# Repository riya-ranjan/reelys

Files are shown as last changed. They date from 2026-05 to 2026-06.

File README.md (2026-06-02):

# Reelys

Reelys are a DIY sonified, light up heely shoe, designed from scratch as part of a capstone project for Stanford CCRMA's MUSIC250A: Physical Interaction Design for Music. 

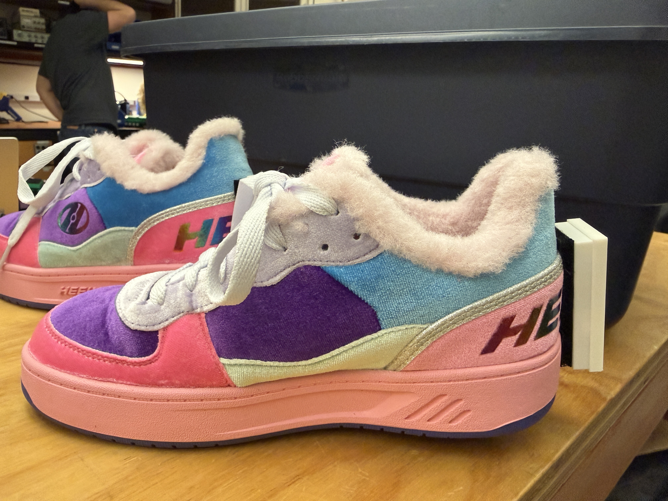
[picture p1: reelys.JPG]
REELYS


## Hardware/Electronics
  * [Seeed XIAO nRF52840 Sense x2](https://www.seeedstudio.com/Seeed-XIAO-BLE-Sense-nRF52840-p-5253.html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)
  * [Rechargeable Lithium Polymer Battery x2](https://ydlbattery.com/products/ydl-3-7v-150mah-352025-rechargeable-lipo-battery-with-jst-connector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)
  * [Adapter Cables Polymer Battery x2](https://www.amazon.com/dp/B07NWD5NTN?ref=ppx_yo2ov_dt_b_fed_asin_title)
  * 1 pair of your favorite Heelys. I got [these](https://heelys.com/products/rezerve-low-neon-pink-violet-aruba?variant=45104283877527) since they were only 30 bucks on sale.
  * Casings for the chips + batteries to velcro to the back of the shoe. See `assembly/Reelys-Casing-Final.stl` for a 3D print you can use for this. 

## Software

This project uses Arduino code for obtaining IMU readings from the Seeed boards, and Max for doing sound synthesis. 

## Arduino and Python Libraries

**Board package** (install via Arduino IDE → Tools → Board → Boards Manager…):

  * **Seeed nRF52 Boards** — v1.1.12.
    To make the package available in Boards Manager, first add the index URL under **Arduino IDE → Settings → Additional boards manager URLs**:
    `https://files.seeedstudio.com/arduino/package_seeeduino_boards_index.json`

**Libraries** (install via Arduino IDE → Tools → Manage Libraries…):

  * **Seeed Arduino LSM6DS3** — v2.0.5. Driver for the onboard LSM6DS3TR-C IMU.
    https://github.com/Seeed-Studio/Seeed_Arduino_LSM6DS3
  * **MIDI Library** by Francois Best / lathoub — v5.0.2. Wraps Bluefruit's `BLEMidi` transport so the standard `MIDI.sendControlChange(...)` API works over BLE.

**Python (laptop side, debug listener only)** — pinned in `requirements.txt`:

  * **bleak** ≥0.21. If you are using `tools/ble_listener.py` to debug bluetooth connections to your Reelys, install with `pip install -r requirements.txt`.

## Usage

Flash both of your Seeed chips using `test_sketches/imu_ble_midi.ino`. Make sure that you change the 
shoe identity variable at the top of the file between flashes (1 for right shoe, 0 for left shoe).

Once you have your IMUs powered on and strapped to the back of the shoe, they should be recognizable
as `Reelys-L` and `Reelys-R` bluetooth MIDI devices. On Mac, you can connect to these devices using
the Audio Midi Setup app and opening up bluetooth connections in the MIDI Studio. 

Once your bluetooth connection is set up, you can launch the `max_patches/wee_oo.maxpat` patch and hear
sound from both shoes. You may need to recalibrate the patch to the orientation of your Seeed; mine is 
calibrated to changes in z acceleration. Feel free to create your own patches for customized sound design! 

To recharge your batteries, make sure they are connected to your Seeed chip and plug your Seeed chip
into your laptop via the USB-C connection.

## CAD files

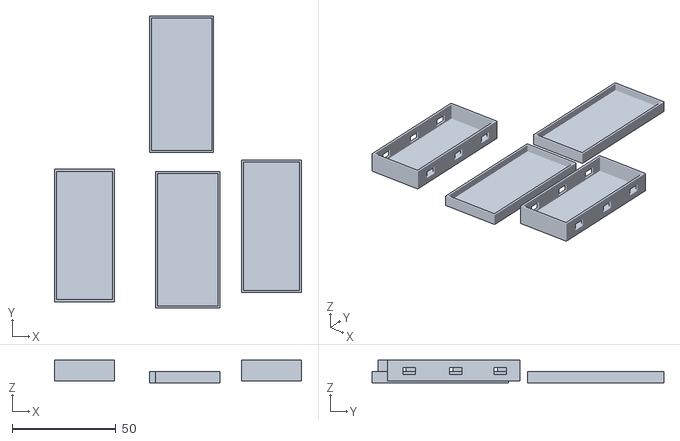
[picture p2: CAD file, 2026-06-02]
assembly/Reelys-Casing-Final.stl
119.5 x 141.0 x 11.0

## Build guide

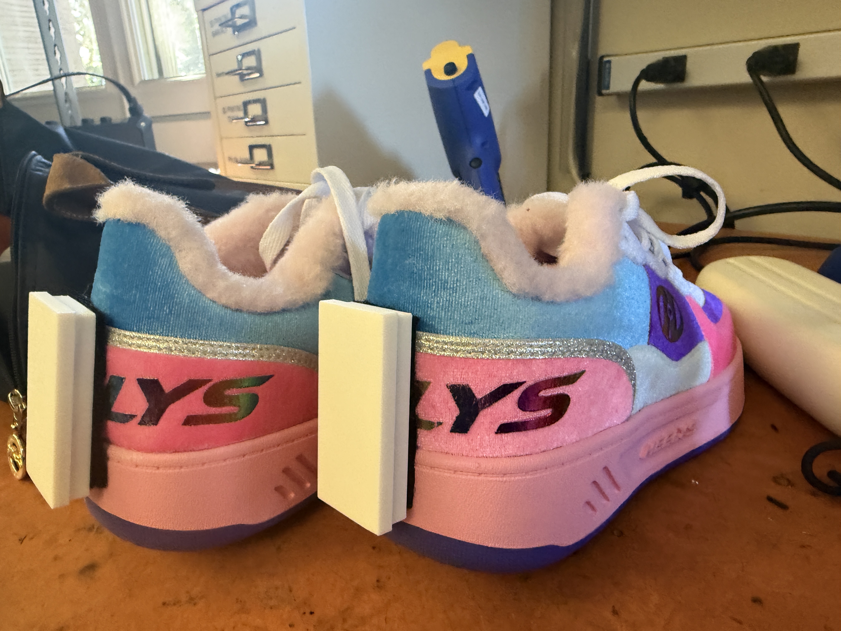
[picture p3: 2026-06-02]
assembly/FINISHED.JPG

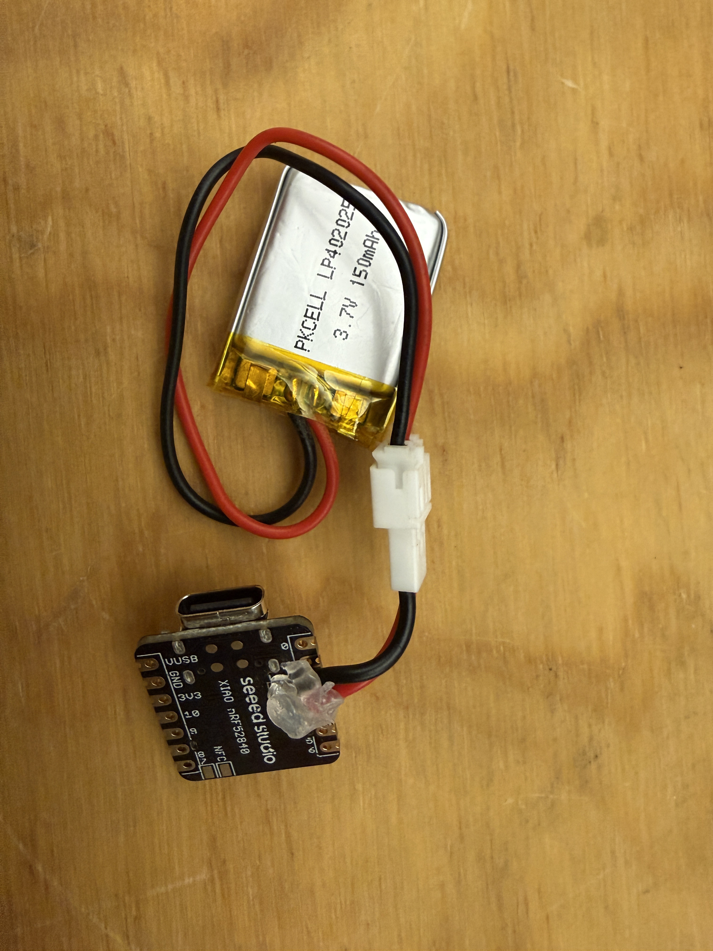
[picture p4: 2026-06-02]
assembly/ELECTRIC_CONNECTION.JPG

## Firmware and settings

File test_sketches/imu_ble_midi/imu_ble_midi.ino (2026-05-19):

// Reelys — imu_ble_midi
// Read the onboard LSM6DS3TR-C IMU on the Seeed XIAO nRF52840 Sense at
// ~50 Hz, advertise as a standard BLE MIDI peripheral, and stream each
// axis as a 7-bit MIDI CC. Keep echoing the same CSV to USB serial so
// the imu_serial manual test still works when plugged in.
//
// This sketch is mutually exclusive with imu_ble.ino — they advertise
// the same device name but expose different BLE services. Flash this
// one when you want sound out of Max; reflash imu_ble.ino if you need
// the raw-float Python debug pipeline.
//
// Change detection / hysteresis:
//   The LSM6DS3 is very sensitive — a stationary shoe still produces
//   small jitter in the IMU readings. Sending a CC for every sample
//   would flood Max with ~300 msg/s of mostly-redundant updates. So
//   each CC is only sent when its newly-scaled 7-bit value differs
//   from the last *sent* value by at least CC_DELTA_THRESHOLD LSBs.
//   At rest: near-zero BLE traffic. In motion: bounded at 6 msgs per
//   sample × 50 Hz = 300 msg/s worst case.
//   Tune CC_DELTA_THRESHOLD up if Max still feels jittery, or down
//   (to 1) if small gestures aren't moving the CCs.
//
// Build / upload:
//   Board:     Tools → Board → Seeed nRF52 Boards → "Seeed XIAO nRF52840 Sense"
//   Libraries: - "Seeed Arduino LSM6DS3" via Library Manager (same as imu_ble)
//              - "MIDI Library" by FortySevenEffects via Library Manager  <-- NEW
//                https://github.com/FortySevenEffects/arduino_midi_library
//              The Bluefruit nRF52 library is bundled with the Seeed nRF52
//              board package — no separate install needed.
//   Upload:    Upload (→) in the IDE; double-tap reset if it doesn't enumerate.
//
// Pair on macOS:
//   1. Open Audio MIDI Setup.app → Window → Show MIDI Studio.
//   2. Double-click the "Bluetooth" icon.
//   3. "Reelys-L" should appear in the device list — click "Connect".
//   4. The shoe is now a system-wide MIDI source. Any DAW or Max patch
//      can read its CCs via standard MIDI input.
//
// Verify in Max:
//   With one shoe connected: drop six [ctlin N] objects (N=1..6), each into
//   a number box. Right-click each ctlin → Input → select the shoe's name
//   ("Reelys-L" or "Reelys-R") to avoid crosstalk with other MIDI devices.
//   With both shoes connected: use [ctlin N C] where C is the channel
//   (1 for left, 2 for right) — e.g. [ctlin 1 1] for left ax, [ctlin 1 2]
//   for right ax. Channel filtering is how Max distinguishes the two shoes.
//   Wiggle the shoe — values should update when motion exceeds the
//   hysteresis threshold (default 2 LSB on a 0–127 scale).
//
// BLE protocol:
//   Device name:    "Reelys-L"  (left shoe; right shoe will use "-R")
//   Service UUID:   03B80E5A-EDE8-4B33-A024-BC7BDC5DA0EF  (standard BLE MIDI)
//   Char   UUID:    7772E5DB-3868-4112-A1A9-F2669D106BF3  (standard BLE MIDI)
//   These UUIDs come from Apple's BLE MIDI 1.0 spec — do not invent custom ones.
//
// Shoe identity (build-time switch):
//   Flip the REELYS_SHOE_RIGHT macro near the top of the code from 0 to 1
//   before flashing the *right* shoe. That selects:
//     0 → device name "Reelys-L", MIDI channel 1  (default; left shoe)
//     1 → device name "Reelys-R", MIDI channel 2  (right shoe)
//   CC numbers (1..6) are identical on both shoes; Max distinguishes left
//   vs right by channel. The sketch is otherwise identical between shoes,
//   so any future tweak (hysteresis, sample rate, scaling) lives in one
//   place and applies to both. Remember to flip the macro back to 0 before
//   reflashing the left shoe.
//
// Calibration — tilt-focused:
//   The accel range is clamped to ±1 g, not the full ±16 g the sensor reports.
//   Rationale: gravity projected onto any single axis is always within ±1 g,
//   so for tilt sensing the entire 0..127 CC range is spent on orientation
//   instead of wasted on impact headroom. The tradeoff is that any accel
//   spike above 1 g (heel-strike, stomp) saturates the accel CCs at 0 or 127.
//   This is intentional — stomp / impact handling will widen the range later.
//   Gyro stays at ±2000°/s (still useful as "how fast the shoe is rotating").
//
// MIDI CC mapping (channel 1):
//   CC 1 → ax (accel X, forward)   range ±1 g     mapped to 0..127
//   CC 2 → ay (accel Y, lateral)   range ±1 g     mapped to 0..127
//   CC 3 → az (accel Z, vertical)  range ±1 g     mapped to 0..127
//   CC 4 → gx (gyro X)             range ±2000°/s mapped to 0..127
//   CC 5 → gy (gyro Y)             range ±2000°/s mapped to 0..127
//   CC 6 → gz (gyro Z)             range ±2000°/s mapped to 0..127
//   Stationary, shoe flat: CC1/CC2 ≈ 64, CC3 ≈ 127 (1 g of gravity pins az
//   to the top of the ±1 g range), CC4..6 ≈ 64. Tilting the shoe sweeps
//   CC1/CC2 across the full 0..127 range as the gravity vector rotates.
//
// CSV format (USB serial, one line per sample — unchanged from imu_serial /
// imu_ble, and printed every sample regardless of BLE connection state):
//   timestamp_ms,ax,ay,az,gx,gy,gz

#include <bluefruit.h>
#include <MIDI.h>
#include "LSM6DS3.h"
#include "Wire.h"

// ---------------- Shoe identity (build-time) ----------------

// Flip to 1 before flashing the right shoe; flip back to 0 before flashing
// the left shoe. See the "Shoe identity" block in the header comment.
#define REELYS_SHOE_RIGHT 1

#if REELYS_SHOE_RIGHT
  static const char*   REELYS_DEVICE_NAME = "Reelys-R";
  static const uint8_t MIDI_CHANNEL       = 2;
#else
  static const char*   REELYS_DEVICE_NAME = "Reelys-L";
  static const uint8_t MIDI_CHANNEL       = 1;
#endif

// ---------------- IMU ----------------
static LSM6DS3 imu(I2C_MODE, 0x6A);
static const unsigned long SAMPLE_PERIOD_MS = 20;  // ~50 Hz

// ---------------- MIDI mapping ----------------

// Accel clamp is set to ±1 g — tilt-focused. See the "Calibration" block in
// the header comment for the full rationale and the impact-saturation tradeoff.
static const float   ACCEL_RANGE_G   = 1.0f;
static const float   GYRO_RANGE_DPS  = 2000.0f;
// MIDI_CHANNEL is defined in the "Shoe identity" block above (1 = left, 2 = right).

// CC numbers per IMU axis, in [ax, ay, az, gx, gy, gz] order.
static const uint8_t CC_NUMS[6] = { 1, 2, 3, 4, 5, 6 };

// Hysteresis on the 7-bit CC value — only send when the new scaled value
// has moved at least this many LSBs from the last sent value. 2 LSB on a
// 0..127 scale is ~1.6% of full range, enough to swallow stationary IMU
// jitter while still catching small intentional gestures.
static const int CC_DELTA_THRESHOLD = 2;

// Sentinel 255 is out-of-range for a 7-bit CC, so the first scaled sample
// always exceeds the delta threshold and is sent — that gives Max a baseline.
static uint8_t cc_last[6] = { 255, 255, 255, 255, 255, 255 };

// ---------------- BLE MIDI ----------------

static BLEDis   bledis;
static BLEMidi  blemidi;
MIDI_CREATE_BLE_INSTANCE(blemidi);

// ---------------- helpers ----------------

static void halt(const char* reason) {
  for (;;) {
    Serial.print("[FATAL] ");
    Serial.println(reason);
    delay(1000);
  }
}

// Map a signed float into a 7-bit MIDI CC value with hard clamping.
// 0 maps to 64 (mid-range), ±range_abs maps to 0/127.
static uint8_t scaleToCC(float value, float range_abs) {
  if (value >  range_abs) value =  range_abs;
  if (value < -range_abs) value = -range_abs;
  float normalized = (value + range_abs) / (2.0f * range_abs);  // 0..1
  int cc = (int)(normalized * 127.0f + 0.5f);
  if (cc < 0)   cc = 0;
  if (cc > 127) cc = 127;
  return (uint8_t)cc;
}

static void startAdvertising() {
  Bluefruit.Advertising.addFlags(BLE_GAP_ADV_FLAGS_LE_ONLY_GENERAL_DISC_MODE);
  Bluefruit.Advertising.addTxPower();
  Bluefruit.Advertising.addService(blemidi);
  Bluefruit.ScanResponse.addName();  // name in scan response keeps adv packet under 31 bytes
  Bluefruit.Advertising.restartOnDisconnect(true);
  Bluefruit.Advertising.setInterval(32, 244);   // units of 0.625 ms → 20–152.5 ms
  Bluefruit.Advertising.setFastTimeout(30);
  Bluefruit.Advertising.start(0);               // 0 = advertise forever
}

// ---------------- Arduino entrypoints ----------------

void setup() {
  Serial.begin(115200);
  unsigned long t0 = millis();
  while (!Serial && (millis() - t0) < 2000) {
    delay(10);
  }

  if (imu.begin() != 0) {
    halt("LSM6DS3 init failed");
  }

  // BANDWIDTH_MAX must be set before Bluefruit.begin(). Not strictly required
  // for BLE MIDI's tiny 5-byte packets, but matches imu_ble and gives headroom
  // if all six CCs ever bundle into one connection event during fast motion.
  Bluefruit.configPrphBandwidth(BANDWIDTH_MAX);

  if (!Bluefruit.begin()) {
    halt("Bluefruit init failed");
  }
  Bluefruit.setName(REELYS_DEVICE_NAME);
  Bluefruit.setTxPower(4);  // dBm

  bledis.setManufacturer("Reelys");
  bledis.setModel(REELYS_DEVICE_NAME);
  bledis.begin();

  // MIDI.begin() internally calls blemidi.begin() to register the GATT service.
  // OMNI just controls input filtering — we only send, so it's a no-op for us.
  MIDI.begin(MIDI_CHANNEL_OMNI);

  startAdvertising();

  Serial.println("# Reelys / imu_ble_midi");
  Serial.println("# Streaming IMU over BLE MIDI + USB serial");
  Serial.print  ("# Device name: ");
  Serial.print  (REELYS_DEVICE_NAME);
  Serial.println(" (BLE MIDI peripheral)");
  Serial.println("# Sample rate: ~50 Hz");
  Serial.println("# CC hysteresis: 2 LSB (sends suppressed below threshold)");
  Serial.println("# Units: accel in g, gyro in deg/s");
  Serial.print  ("# CC mapping: CC1=ax CC2=ay CC3=az CC4=gx CC5=gy CC6=gz (ch ");
  Serial.print  (MIDI_CHANNEL);
  Serial.println(")");
  Serial.println("timestamp_ms,ax,ay,az,gx,gy,gz");
}

void loop() {
  unsigned long t = millis();

  float data[6];
  data[0] = imu.readFloatAccelX();
  data[1] = imu.readFloatAccelY();
  data[2] = imu.readFloatAccelZ();
  data[3] = imu.readFloatGyroX();
  data[4] = imu.readFloatGyroY();
  data[5] = imu.readFloatGyroZ();

  // Always print raw CSV to USB serial — independent of BLE state — so the
  // imu_serial manual test still works when plugged in for debugging.
  Serial.print(t);
  for (int i = 0; i < 6; i++) {
    Serial.print(',');
    Serial.print(data[i], 4);
  }
  Serial.println();

  // Stream changed CCs over BLE MIDI when a central is connected and ready.
  if (Bluefruit.connected() && blemidi.notifyEnabled()) {
    const float ranges[6] = {
      ACCEL_RANGE_G, ACCEL_RANGE_G, ACCEL_RANGE_G,
      GYRO_RANGE_DPS, GYRO_RANGE_DPS, GYRO_RANGE_DPS,
    };
    for (int i = 0; i < 6; i++) {
      uint8_t cc_new = scaleToCC(data[i], ranges[i]);
      int delta = (int)cc_new - (int)cc_last[i];
      if (delta < 0) delta = -delta;
      if (delta >= CC_DELTA_THRESHOLD) {
        MIDI.sendControlChange(CC_NUMS[i], cc_new, MIDI_CHANNEL);
        cc_last[i] = cc_new;
      }
    }
  }

  unsigned long elapsed = millis() - t;
  if (elapsed < SAMPLE_PERIOD_MS) {
    delay(SAMPLE_PERIOD_MS - elapsed);
  }
}

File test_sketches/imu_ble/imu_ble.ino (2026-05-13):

// Reelys — imu_ble
// Read the onboard LSM6DS3TR-C IMU on the Seeed XIAO nRF52840 Sense
// at ~50 Hz, stream samples over BLE as notifications, and keep
// echoing the same CSV to USB serial (so the imu_serial manual test
// still works when plugged in).
//
// Build / upload:
//   Board:    Tools → Board → Seeed nRF52 Boards → "Seeed XIAO nRF52840 Sense"
//   Library:  "Seeed Arduino LSM6DS3" via Library Manager.
//             The Bluefruit nRF52 library is bundled with the board package
//             — no separate install needed.
//   Upload:   Upload (→) in the IDE; double-tap reset if it doesn't enumerate.
//
// Observe:
//   - USB:    Tools → Serial Monitor, baud 115200. Same CSV format as imu_serial.
//   - BLE:    nRF Connect on phone → scan → "Reelys-L" should appear.
//             Connect, expand the custom service, enable notifications on the
//             characteristic to see 24-byte payloads stream in.
//   - Laptop: tools/ble_listener.py (added in the next step).
//
// BLE protocol:
//   Device name:        "Reelys-L"  (left shoe; right shoe will use "-R")
//   Service UUID:       9E6647DB-3EEC-42B6-8349-A95113E65082
//   Char   UUID:        AE7799DA-9123-45D5-84F9-20B5C3F7F6F4
//   Char   properties:  NOTIFY (no read/write)
//   Payload:            24 bytes = 6 IEEE 754 floats, little-endian, in order
//                       ax, ay, az, gx, gy, gz
//                       accel in g, gyro in deg/s
//
// CSV format (USB serial, one line per sample):
//   timestamp_ms,ax,ay,az,gx,gy,gz

#include <bluefruit.h>
#include "LSM6DS3.h"
#include "Wire.h"

// ---------------- IMU ----------------

static LSM6DS3 imu(I2C_MODE, 0x6A);
static const unsigned long SAMPLE_PERIOD_MS = 20;  // ~50 Hz

// ---------------- BLE ----------------

// 128-bit UUIDs in little-endian (wire) byte order — i.e. the textual
// UUID with its bytes reversed. The "human" UUIDs are in the header
// comment above. Don't edit one without updating the other.

// Service: 9E6647DB-3EEC-42B6-8349-A95113E65082
static const uint8_t SERVICE_UUID[16] = {
  0x82, 0x50, 0xE6, 0x13, 0x51, 0xA9, 0x49, 0x83,
  0xB6, 0x42, 0xEC, 0x3E, 0xDB, 0x47, 0x66, 0x9E
};

// Characteristic: AE7799DA-9123-45D5-84F9-20B5C3F7F6F4
static const uint8_t IMU_CHAR_UUID[16] = {
  0xF4, 0xF6, 0xF7, 0xC3, 0xB5, 0x20, 0xF9, 0x84,
  0xD5, 0x45, 0x23, 0x91, 0xDA, 0x99, 0x77, 0xAE
};

static BLEService        imuService(SERVICE_UUID);
static BLECharacteristic imuChar(IMU_CHAR_UUID);

// ---------------- helpers ----------------

static void halt(const char* reason) {
  for (;;) {
    Serial.print("[FATAL] ");
    Serial.println(reason);
    delay(1000);
  }
}

static void startAdvertising() {
  Bluefruit.Advertising.addFlags(BLE_GAP_ADV_FLAGS_LE_ONLY_GENERAL_DISC_MODE);
  Bluefruit.Advertising.addTxPower();
  Bluefruit.Advertising.addService(imuService);
  Bluefruit.ScanResponse.addName();  // name in scan response keeps adv packet under 31 bytes
  Bluefruit.Advertising.restartOnDisconnect(true);
  Bluefruit.Advertising.setInterval(32, 244);   // units of 0.625 ms → 20–152.5 ms
  Bluefruit.Advertising.setFastTimeout(30);
  Bluefruit.Advertising.start(0);               // 0 = advertise forever
}

// ---------------- Arduino entrypoints ----------------

void setup() {
  Serial.begin(115200);
  unsigned long t0 = millis();
  while (!Serial && (millis() - t0) < 2000) {
    delay(10);
  }

  if (imu.begin() != 0) {
    halt("LSM6DS3 init failed");
  }

  // Must be set before Bluefruit.begin(). Default ATT MTU is 23, which leaves
  // only 20 bytes for notification payloads — our 24-byte payload gets
  // truncated. BANDWIDTH_MAX bumps the peripheral MTU to 247 so notifications
  // can carry the full 24 bytes once the central negotiates upward.
  Bluefruit.configPrphBandwidth(BANDWIDTH_MAX);

  if (!Bluefruit.begin()) {
    halt("Bluefruit init failed");
  }
  Bluefruit.setName("Reelys-L");
  Bluefruit.setTxPower(4);  // dBm

  imuService.begin();

  imuChar.setProperties(CHR_PROPS_NOTIFY);
  imuChar.setPermission(SECMODE_OPEN, SECMODE_NO_ACCESS);
  imuChar.setFixedLen(24);  // 6 floats
  imuChar.begin();

  startAdvertising();

  Serial.println("# Reelys / imu_ble");
  Serial.println("# Streaming IMU over BLE + USB serial");
  Serial.println("# Device name: Reelys-L");
  Serial.println("# Sample rate: ~50 Hz");
  Serial.println("# Units: accel in g, gyro in deg/s");
  Serial.println("timestamp_ms,ax,ay,az,gx,gy,gz");
}

void loop() {
  unsigned long t = millis();

  float data[6];
  data[0] = imu.readFloatAccelX();
  data[1] = imu.readFloatAccelY();
  data[2] = imu.readFloatAccelZ();
  data[3] = imu.readFloatGyroX();
  data[4] = imu.readFloatGyroY();
  data[5] = imu.readFloatGyroZ();

  if (Bluefruit.connected()) {
    imuChar.notify(data, sizeof(data));
  }

  Serial.print(t);
  for (int i = 0; i < 6; i++) {
    Serial.print(',');
    Serial.print(data[i], 4);
  }
  Serial.println();

  unsigned long elapsed = millis() - t;
  if (elapsed < SAMPLE_PERIOD_MS) {
    delay(SAMPLE_PERIOD_MS - elapsed);
  }
}

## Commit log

2026-05-13 basic files to read from XIAO IMU
2026-05-22 arduino / python library spec updates
2026-06-02 assembly stuff
    [Reelys-Casing-Final.stl]
